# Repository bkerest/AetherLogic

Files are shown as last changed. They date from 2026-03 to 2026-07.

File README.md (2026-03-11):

# AetherLogic Firmware

Firmware για το σύστημα παρακολούθησης ποιότητας αέρα και θορύβου σε βιομηχανικά περιβάλλοντα βαφής αλουμινίου.

## Επισκόπηση

Το σύστημα αποτελείται από:
- **Sensor Nodes** (ESP32-C3): Αυτόνομοι κόμβοι με μπαταρία που συλλέγουν δεδομένα από αισθητήρες
- **Gateway** (ESP32-S3): Κεντρική πύλη που λαμβάνει δεδομένα μέσω LoRa και τα προωθεί σε MQTT broker

## Hardware

### Sensor Node (ESP32-C3)
| Αισθητήρας | Μέτρηση |
|---|---|
| BME680 | Θερμοκρασία, Υγρασία, Πίεση, VOC |
| SCD40 | CO₂ |
| ZH03B | Σωματίδια (PM2.5, PM10) |
| INMP441 | Θόρυβος (I2S) |

### Gateway (ESP32-S3)
- SX1276 LoRa module
- WiFi σύνδεση με MQTT broker

### LoRa Configuration
- Συχνότητα: 868 MHz
- Spreading Factor: SF10
- Bandwidth: 125 kHz

## Δομή Repository

```
aetherlogic/firmware/
├── sensor-node/          # ESP32-C3 firmware
│   └── sensor-node.ino
├── gateway/              # ESP32-S3 firmware
│   └── gateway.ino
└── docs/
    └── pinouts.md
    └──docs/gerber/
        └── Gerber_GateWay.zip        # Σχέδια πλακέτας Πύλης
        └── Gerber_Node.zip           # Σχέδια πλακέτας αισθητήρων
        └── Gerber_Node_Power.zip     # Σχέδια πλακέτας τροφοδοσίας αισθητήρων
    └──docs/grafana/
        └── AetherLogic - Main Dashboard-1773261228574.json     # Κυρίως Πίνακας ελέγχου με κάτοψη εργοστασίου
        └── AetherLogic - Nodes Dashboard-1773261255099.json    # Πίνακας ελέγχου ανά κόμβο
        └── alert-rules-1773261341571.json                      # Κανόνες ειδοποιήσεων
        └── contact-points-1773261295272.json                   # Σημεία επαφής
        └── elvial_floorplan.svg                                # Κάτοψη εργοστασίου σε μορφή svg
        └── JS_Initialization.js                                # Αρχείο αρχικοποίησης Main Dashboard
        └── JS_Render_Code.js                                   # Αρχείο λειτουργίας js/react Main Dashboard
    └──docs/influx/
        └── influxdb-schema.md    # Λειτουργικά ερωτήματα Influx και downsampling
    └──docs/monitoring/
        └── docker-compose.yml    # Αρχείο ρυθμίσων docker station
    └──docs/stl/
        └── GATEWAY_BOTTOM.stl    # Εκτυπώσιμο (3D) περιβλήματος πύλης
        └── GATEWAY_CAP.stl       # Εκτυπώσιμο (3D) καπακιού πύλης
        └── NODE_BOTTOM.stl       # Εκτυπώσιμο (3D) περιβλήματος κόμβου
        └── NODE_CAP.stl          # Εκτυπώσιμο (3D) καπακιού κόμβου
        └── PCB_HOLDER.stl        # Εκτυπώσιμο (3D) βάσης στήριξης PCB
    └──docs/telegraf/
        └── telegraf.conf         # Αρχείο ρυθμίσεων telegraf
```

## Απαιτήσεις

- Arduino IDE 2.x
- ESP32 Board Package (by Espressif)
- Βιβλιοθήκες:
  - RadioLib (LoRa)
  - Adafruit BME680
  - Sensirion SCD4x
  - PubSubClient (MQTT)

## Εγκατάσταση

1. Άνοιξε το Arduino IDE
2. Εγκατάστησε το ESP32 board package:
   - File → Preferences → Additional Board Manager URLs:
   - `https://raw.githubusercontent.com/espressif/arduino-esp32/gh-pages/package_esp32_index.json`
3. Tools → Board → ESP32 → επίλεξε το αντίστοιχο board
4. Άνοιξε τον φάκελο `sensor-node/` ή `gateway/` ανάλογα

## Backend

Τα δεδομένα αποστέλλονται σε MQTT broker (EMQX) και αποθηκεύονται σε InfluxDB μέσω Telegraf. Visualization με Grafana.

Dashboard: https://aetherlogic.eu/

## Άδεια

Μέρος πτυχιακής εργασίας - ΕΑΠ - ΠΛΗ40

## Συγγραφέας

Βασίλειος Κερεστετζής - Υπό την επίβλεψη του Καθηγητή Μηνά Δασυγένη

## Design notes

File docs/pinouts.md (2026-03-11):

# Pinouts Documentation

## Sensor Node - ESP32-C3

### Analog Inputs (ADC1)
| Λειτουργία | ESP32-C3 Pin | Σημείωση |
|---|---|---|
| Battery | GPIO0 | ADC1_CH0 |
| Microphone | GPIO1 | ADC1_CH1 |

### Power Control
| Λειτουργία | ESP32-C3 Pin | Σημείωση |
|---|---|---|
| ZH03B Power  | GPIO5 | Boost EN |
| Sensors Power| GPIO8 | P-MOS Gate |

### I2C Bus (BME680, SCD40)
| Σήμα | ESP32-C3 Pin |
|---|---|
| SDA  | GPIO19 |
| SCL  | GPIO18 |

### ZH03B (UART - RX only)
| ZH03B Pin | ESP32-C3 Pin | Σημείωση |
|---|---|---|
| TXD | GPIO4 | ZH_RX_PIN |
| VCC | 5V (via boost) | Ελέγχεται από GPIO5 |
| GND | GND | |

### LoRa Module (SX1276)
| SX1276 Pin | ESP32-C3 Pin | Σημείωση |
|---|---|---|
| VCC | 3.3V | |
| GND | GND | |
| SCK | GPIO6 | SPI CLK  |
| MISO | GPIO2 | SPI MISO |
| MOSI | GPIO7 | SPI MOSI |
| NSS | GPIO10 | SPI CS |
| RST | GPIO9 | Reset |
| DIO0 | GPIO3 | IRQ |

---

## Gateway - ESP32-S3

### LoRa Module (SX1276) - FSPI
| SX1276 Pin | ESP32-S3 Pin | Σημείωση |
|---|---|---|
| VCC | 3.3V | |
| GND | GND | |
| SCK | GPIO4 | FSPI CLK |
| MISO | GPIO5 | FSPI MISO|
| MOSI | GPIO6 | FSPI MOSI|
| NSS | GPIO7 | FSPI CS  |
| RST | GPIO15 | Reset |
| DIO0 | GPIO16 | IRQ |

### TFT Display (ST7789 320x240) - HSPI
| TFT Pin | ESP32-S3 Pin | Σημείωση |
|---|---|---|
| SCLK | GPIO9 | HSPI CLK |
| MOSI | GPIO10 | HSPI MOSI|
| CS | GPIO13 | Chip Select |
| DC | GPIO12 | Data/Command |
| RST | GPIO11 | Reset |
| BL | GPIO41 | Backlight (timeout: 20s) |

### User Interface
| Λειτουργία | ESP32-S3 Pin | Σημείωση |
|---|---|---|
| Button | GPIO0 | Long press: 3s |

---

## I2C Addresses (Sensor Node)

| Συσκευή | Address |
|---|---|
| BME680  | 0x77 |
| SCD40 | 0x62 |

---

## Configuration Defaults

### Sensor Node
| Παράμετρος | Τιμή | Σημείωση |
|---|---|---|
| Node ID | 1 | |
| Sleep Time | 300s | 5 λεπτά  |
| Warmup Time| 25s  | |
| LoRa Profile| 2 | |
| AES Key | "MySecretKey12345" | 16 bytes |

### Gateway
| Παράμετρος | Τιμή | Σημείωση |
|---|---|---|
| MQTT Server| d0a16fcc.ala.eu-central-1.emqxsl.com | EMQX Cloud |
| MQTT Port  | 8883 | TLS |
| MQTT Topic | lora/sensors | |
| LoRa Profile| 3 | SF10 Long Range |
| Hostname | s3gateway | |
| NTP Server | pool.ntp.org | |
| Timezone | GMT+2 (+DST) | Ελλάδα |

---

## Σημειώσεις

1. **ESP32-C3**: Χρησιμοποιεί P-MOS για power control των αισθητήρων (GPIO8)
2. **ESP32-S3**: Διπλό SPI bus - FSPI για LoRa, HSPI για TFT
3. **SX1276**: Λειτουργεί στα 3.3V - ΜΗΝ συνδέσετε σε 5V
4. **ZH03B**: Χρειάζεται 5V από boost converter (ελέγχεται από GPIO5)
5. **TFT Backlight**: Αυτόματο timeout μετά από 20s αδράνειας
6. **Magic Number**: 0xCAFE για validation των settings στη μνήμη

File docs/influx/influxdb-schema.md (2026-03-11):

# InfluxDB Schema & Data Pipeline - AetherLogic IoT System

## Περιεχόμενα
1. [Γενική Επισκόπηση](#γενική-επισκόπηση)
2. [Buckets & Retention Policies](#buckets--retention-policies)
3. [Measurements & Schema](#measurements--schema)
4. [Downsampling Tasks](#downsampling-tasks)
5. [Queries & Aggregations](#queries--aggregations)
6. [Storage Calculations](#storage-calculations)

---

## Γενική Επισκόπηση

Το σύστημα AetherLogic χρησιμοποιεί **InfluxDB v2** ως time-series database για την αποθήκευση δεδομένων αισθητήρων και gateway health metrics.

### Ροή Δεδομένων

```
┌─────────────┐     LoRa      ┌─────────┐    MQTT     ┌────────────┐
│ Sensor Node │ ──────────────>│ Gateway │ ──────────> │ EMQX Broker│
└─────────────┘   868MHz       └─────────┘   TLS:8883  └────────────┘
                                                              │
                                                              │ MQTT
                                                              ▼
                                                        ┌──────────┐
                                                        │ Telegraf │
                                                        └──────────┘
                                                              │
                                                              │ Line Protocol
                                                              ▼
┌─────────────────────────────────────────────────────────────────────┐
│                          InfluxDB v2                                │
├─────────────────────────────────────────────────────────────────────┤
│  Bucket: eap_plh40       (90 days)   ← Raw 5min data               │
│  Bucket: eap_plh40_1h    (1 year)    ← Hourly aggregates           │
│  Bucket: eap_plh40_1d    (5 years)   ← Daily aggregates            │
└─────────────────────────────────────────────────────────────────────┘
                                 │
                                 │ Flux Queries
                                 ▼
                           ┌──────────┐
                           │ Grafana  │
                           └──────────┘
```

---

## Buckets & Retention Policies

### Σχεδιασμός Buckets

Το σύστημα χρησιμοποιεί **3-tier retention strategy** για βέλτιστη χρήση αποθηκευτικού χώρου:

| Bucket | Retention | Data Interval | Purpose | Requirement |
|---|---|---|---|---|
| `eap_plh40` | 90 days | 5 minutes | Recent detailed data | FR-STOR-02 (partial) |
| `eap_plh40_1h` | 1 year | 1 hour avg | Historical trends | FR-STOR-02 (≥1 year) ✅ |
| `eap_plh40_1d` | 5 years | 1 day avg | Long-term analysis | FR-STOR-04 ✅ |

### Δημιουργία Buckets (InfluxDB CLI)

```bash
# Bucket 1: Raw data (90 days)
influx bucket create \
  --name eap_plh40 \
  --org "Hellenic Open University" \
  --retention 90d

# Bucket 2: Hourly aggregates (1 year)
influx bucket create \
  --name eap_plh40_1h \
  --org "Hellenic Open University" \
  --retention 365d

# Bucket 3: Daily aggregates (5 years)
influx bucket create \
  --name eap_plh40_1d \
  --org "Hellenic Open University" \
  --retention 1825d
```

### Δημιουργία Buckets (InfluxDB UI)

1. Ανοίξτε InfluxDB UI: `http://192.168.2.5:8086`
2. Πλοηγηθείτε: **Data** → **Buckets**
3. Κάντε κλικ: **+ Create Bucket**
4. Συμπληρώστε:
   - **Name**: `eap_plh40`
   - **Delete Data**: **Older than 90 days**
   - **Organization**: `Hellenic Open University`
5. Επαναλάβετε για `eap_plh40_1h` (365d) και `eap_plh40_1d` (1825d)

---

## Measurements & Schema

### Measurement 1: `air_quality`

Δεδομένα αισθητήρων από LoRa nodes.

#### Tags (Indexed)

| Tag | Type | Description | Example |
|-----|---|---|---|
| `id` | string | Node ID (από device configuration) | "1", "2", "3" |
| `gw` | string | Gateway ID (ESP32-S3 MAC-based) | "ESP32S3ABC123" |
| `node` | string | Friendly node name | "node_01", "FactoryNode_01" |

#### Fields (Not Indexed)

| Field | Type | Unit | Description | Range |
|---|---|---|---|---|
| `t` | float | °C | Temperature | -40 to 85 |
| `h` | float | % | Relative Humidity | 0 to 100 |
| `p` | float | hPa | Atmospheric Pressure | 300 to 1100 |
| `alt` | float | m | Calculated Altitude | -500 to 9000 |
| `iaq` | float | - | Indoor Air Quality Index | 0 to 500 |
| `tvoc` | float | kΩ | Gas Resistance (BME680) | 0 to 500 |
| `co2` | integer | ppm | CO₂ Concentration (SCD40) | 400 to 5000 |
| `pm1` | integer | µg/m³ | PM1.0 Particulate Matter | 0 to 1000 |
| `pm25` | integer | µg/m³ | PM2.5 Particulate Matter | 0 to 1000 |
| `pm10` | integer | µg/m³ | PM10 Particulate Matter | 0 to 1000 |
| `noise` | float | dB SPL | Noise Level | 30 to 130 |
| `batt` | float | V | Battery Voltage | 2.8 to 4.2 |
| `rssi` | integer | dBm | LoRa Signal Strength | -120 to -30 |

#### Example Line Protocol

```
air_quality,id=1,gw=ESP32S3ABC123,node=node_01 t=24.5,h=45.2,p=1013.25,alt=120.5,iaq=125,tvoc=45.23,co2=450,pm1=8,pm25=12,pm10=25,noise=65.3,batt=3.82,rssi=-85 1706097045000000000
```

#### Example JSON Payload (from MQTT)

```json
{
  "timestamp": "2024-01-24T14:30:45+02:00",
  "gw": "ESP32S3ABC123",
  "id": 1,
  "node": "node_01",
  "t": 24.5,
  "h": 45.2,
  "p": 1013.25,
  "alt": 120.5,
  "iaq": 125,
  "tvoc": 45.23,
  "co2": 450,
  "pm1": 8,
  "pm25": 12,
  "pm10": 25,
  "noise": 65.3,
  "batt": 3.82,
  "rssi": -85
}
```

---

### Measurement 2: `gateway_health`

Gateway heartbeat και health metrics (κάθε 5 λεπτά).

#### Tags

| Tag | Type | Description | Example |
|-----|---|---|---|
| `gw` | string | Gateway ID | "ESP32S3ABC123" |
| `type` | string | Message type | "heartbeat" |
| `fw` | string | Firmware version | "2.5.2" |

#### Fields

| Field | Type | Unit | Description |
|---|---|---|---|
| `uptime` | integer | seconds | Time since boot |
| `heap` | integer | bytes | Free heap memory |
| `wifi_rssi` | integer | dBm | WiFi signal strength |
| `lora_packets` | integer | count | Total LoRa packets received |
| `buffer` | integer | count | Buffered MQTT messages |
| `ntp_synced` | boolean | - | NTP synchronization status |
| `lora_ok` | boolean | - | LoRa module initialization status |

#### Example Line Protocol

```
gateway_health,gw=ESP32S3ABC123,type=heartbeat,fw=2.5.2 uptime=86400,heap=245760,wifi_rssi=-65,lora_packets=1440,buffer=0,ntp_synced=true,lora_ok=true 1706097045000000000
```

---

## Downsampling Tasks

Τα **InfluxDB Tasks** εκτελούν αυτόματα aggregations για downsampling.

### Task 1: Hourly Downsampling

**Σκοπός**: Υπολογισμός ωριαίων μέσων όρων από raw data (5min).

**Συχνότητα**: Κάθε ώρα (στο :05 λεπτό για να έχει ολοκληρωθεί η προηγούμενη ώρα).

**Flux Script**:

```flux
// Task: Downsample to 1-hour averages
option task = {
  name: "downsample_1h_air_quality",
  every: 1h,
  offset: 5m  // Run at :05 past the hour
}

from(bucket: "eap_plh40")
  |> range(start: -2h, stop: -1h)  // Process previous hour
  |> filter(fn: (r) => r._measurement == "air_quality")
  |> aggregateWindow(
      every: 1h,
      fn: mean,
      createEmpty: false
    )
  |> to(
      bucket: "eap_plh40_1h",
      org: "Hellenic Open University"
    )
```

**Δημιουργία Task (InfluxDB UI)**:

1. **Tasks** → **Create Task**
2. **Name**: `downsample_1h_air_quality`
3. **Every**: `1h`
4. **Offset**: `5m`
5. Paste Flux script
6. **Save**

---

### Task 2: Daily Downsampling

**Σκοπός**: Υπολογισμός ημερήσιων μέσων όρων από hourly data.

**Συχνότητα**: Κάθε μέρα στις 00:10.

**Flux Script**:

```flux
// Task: Downsample to 1-day averages
option task = {
  name: "downsample_1d_air_quality",
  every: 1d,
  offset: 10m  // Run at 00:10
}

from(bucket: "eap_plh40_1h")
  |> range(start: -2d, stop: -1d)  // Process previous day
  |> filter(fn: (r) => r._measurement == "air_quality")
  |> aggregateWindow(
      every: 1d,
      fn: mean,
      createEmpty: false
    )
  |> to(
      bucket: "eap_plh40_1d",
      org: "Hellenic Open University"
    )
```

---

### Task 3: Gateway Health Downsampling (Optional)

**Σκοπός**: Υπολογισμός ημερήσιων aggregations για gateway metrics.

```flux
option task = {
  name: "downsample_1d_gateway_health",
  every: 1d,
  offset: 15m
}

from(bucket: "eap_plh40")
  |> range(start: -2d, stop: -1d)
  |> filter(fn: (r) => r._measurement == "gateway_health")
  |> aggregateWindow(
      every: 1d,
      fn: mean,  // or max/min depending on field
      createEmpty: false
    )
  |> to(
      bucket: "eap_plh40_1d",
      org: "Hellenic Open University"
    )
```

---

## Queries & Aggregations

### Basic Queries (Flux)

#### Query 1: Latest Reading από κάθε Node

```flux
from(bucket: "eap_plh40")
  |> range(start: -1h)
  |> filter(fn: (r) => r._measurement == "air_quality")
  |> filter(fn: (r) => r._field == "t" or r._field == "h" or r._field == "co2")
  |> last()
  |> pivot(rowKey:["_time"], columnKey: ["_field"], valueColumn: "_value")
```

#### Query 2: Μέση Θερμοκρασία τελευταίας εβδομάδας

```flux
from(bucket: "eap_plh40_1h")  // Use hourly data for speed
  |> range(start: -7d)
  |> filter(fn: (r) => r._measurement == "air_quality")
  |> filter(fn: (r) => r._field == "t")
  |> mean()
  |> group(columns: ["node"])
```

#### Query 3: PM2.5 Max per Day (Last Month)

```flux
from(bucket: "eap_plh40_1h")
  |> range(start: -30d)
  |> filter(fn: (r) => r._measurement == "air_quality")
  |> filter(fn: (r) => r._field == "pm25")
  |> aggregateWindow(every: 1d, fn: max)
```

#### Query 4: Gateway Uptime & Health

```flux
from(bucket: "eap_plh40")
  |> range(start: -24h)
  |> filter(fn: (r) => r._measurement == "gateway_health")
  |> filter(fn: (r) => r._field == "uptime" or r._field == "heap")
  |> last()
```

---

### Advanced Aggregations

#### Compute Moving Average (7-day)

```flux
from(bucket: "eap_plh40_1d")
  |> range(start: -90d)
  |> filter(fn: (r) => r._measurement == "air_quality")
  |> filter(fn: (r) => r._field == "co2")
  |> movingAverage(n: 7)  // 7-day moving average
```

#### Detect Threshold Violations (PM2.5 > 35 µg/m³)

```flux
from(bucket: "eap_plh40")
  |> range(start: -24h)
  |> filter(fn: (r) => r._measurement == "air_quality")
  |> filter(fn: (r) => r._field == "pm25")
  |> filter(fn: (r) => r._value > 35)  // WHO 24h guideline
  |> group(columns: ["node"])
  |> count()
```

#### Correlation Analysis (Temperature vs CO2)

```flux
temp = from(bucket: "eap_plh40_1h")
  |> range(start: -7d)
  |> filter(fn: (r) => r._measurement == "air_quality")
  |> filter(fn: (r) => r._field == "t")
  |> drop(columns: ["_measurement"])

co2 = from(bucket: "eap_plh40_1h")
  |> range(start: -7d)
  |> filter(fn: (r) => r._measurement == "air_quality")
  |> filter(fn: (r) => r._field == "co2")
  |> drop(columns: ["_measurement"])

join(
  tables: {temp: temp, co2: co2},
  on: ["_time", "node", "gw"]
)
```

---

## Storage Calculations

### Data Volume Estimation

**Assumptions**:
- **Sensor Nodes**: 5
- **Measurements per Node**: 13 fields (t, h, p, alt, iaq, tvoc, co2, pm1, pm25, pm10, noise, batt, rssi)
- **Sampling Interval**: 5 minutes
- **InfluxDB Point Size**: ~8 bytes per field (average)

#### Tier 1: Raw Data (90 days @ 5min)

```
Points per node per day:
  13 fields × (60 min / 5 min) × 24 hours = 13 × 12 × 24 = 3,744 points/day

Points per node for 90 days:
  3,744 × 90 = 336,960 points

Total points (5 nodes):
  336,960 × 5 = 1,684,800 points

Storage (approximate):
  1,684,800 × 8 bytes = 13.5 MB (compressed: ~3-5 MB)
```

#### Tier 2: Hourly Averages (1 year)

```
Points per node per day:
  13 fields × 24 hours = 312 points/day

Points per node for 1 year:
  312 × 365 = 113,880 points

Total points (5 nodes):
  113,880 × 5 = 569,400 points

Storage:
  569,400 × 8 bytes = 4.6 MB (compressed: ~1-2 MB)
```

#### Tier 3: Daily Averages (5 years)

```
Points per node per day:
  13 fields × 1 = 13 points/day

Points per node for 5 years:
  13 × 365 × 5 = 23,725 points

Total points (5 nodes):
  23,725 × 5 = 118,625 points

Storage:
  118,625 × 8 bytes = 0.95 MB (negligible)
```

#### Total Storage

```
Tier 1 (90d raw):     ~3-5 MB
Tier 2 (1y hourly):   ~1-2 MB
Tier 3 (5y daily):    ~1 MB
----------------------------------
TOTAL:                ~5-8 MB (very manageable!)
```

**Συμπέρασμα**: Το σύστημα με 5 sensor nodes καταναλώνει **<10 MB** για 5 χρόνια ιστορικών δεδομένων με downsampling. Αυτό είναι εξαιρετικά αποδοτικό.

---

## Backup & Restore

### Backup Bucket (InfluxDB CLI)

```bash
# Backup all data from bucket
influx backup /backup/path \
  --bucket eap_plh40 \
  --org "Hellenic Open University"

# Backup specific time range
influx backup /backup/path \
  --bucket eap_plh40 \
  --start 2024-01-01T00:00:00Z \
  --stop 2024-12-31T23:59:59Z
```

### Restore Bucket

```bash
influx restore /backup/path \
  --bucket eap_plh40 \
  --org "Hellenic Open University"
```

### Automated Daily Backup (Cron)

```bash
# Add to crontab: crontab -e
0 2 * * * /usr/bin/influx backup /mnt/backups/influxdb/$(date +\%Y\%m\%d) --bucket eap_plh40 --org "Hellenic Open University"
```

---

## Monitoring & Maintenance

### Health Checks

```bash
# Check bucket size
influx bucket list --org "Hellenic Open University"

# Check task status
influx task list --org "Hellenic Open University"

# View task logs
influx task log list --task-id <TASK_ID>

# Check cardinality (unique tag combinations)
influx cardinality --bucket eap_plh40
```

### Performance Tuning

1. **Indexing**: Tags are automatically indexed, fields are not
2. **Cardinality**: Keep tag cardinality low (<100K unique combinations)
3. **Retention**: Aggressive retention policies reduce storage and improve query speed
4. **Downsampling**: Use pre-aggregated buckets for historical queries

---

## Ικανοποίηση Απαιτήσεων

| Requirement ID | Description | Implementation | Status |
|---|---|---|---|
| FR-STOR-01 | Time-series database | InfluxDB v2 | ✅ |
| FR-STOR-02 | Data retention ≥1 year | `eap_plh40_1h` bucket (365d) | ✅ |
| FR-STOR-03 | Time & node queries | Tags: `id`, `node`, `gw` + timestamp | ✅ |
| FR-STOR-04 | Downsampling | Tasks: 1h, 1d aggregations | ✅ |
| FR-STOR-05 | Automatic deletion | Retention policies (90d, 365d, 1825d) | ✅ |
| FR-STOR-06 | Backup/restore | InfluxDB CLI backup | ✅ (Could Have) |

---

## Πηγές

- [InfluxDB v2 Documentation](https://docs.influxdata.com/influxdb/v2.0/)
- [Flux Language Guide](https://docs.influxdata.com/flux/v0.x/)
- [Telegraf MQTT Consumer](https://github.com/influxdata/telegraf/tree/master/plugins/inputs/mqtt_consumer)
- [Time-Series Data Retention Best Practices](https://www.influxdata.com/blog/tldr-influxdb-tech-tips-august-27-2020/)

---

**Document Version**: 1.0
**Last Updated**: 24 Ιανουαρίου 2026
**Author**: Vasilis Kerestetzis AetherLogic Project - Hellenic Open University

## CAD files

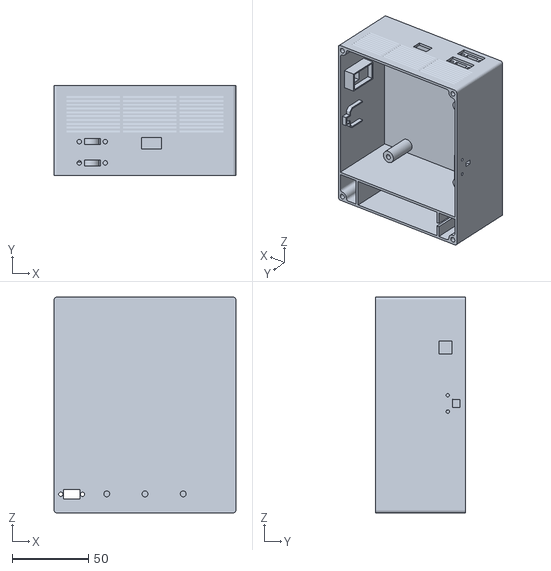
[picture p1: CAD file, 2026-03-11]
docs/stl/NODE_BOTTOM.stl
119.0 x 59.0 x 141.4

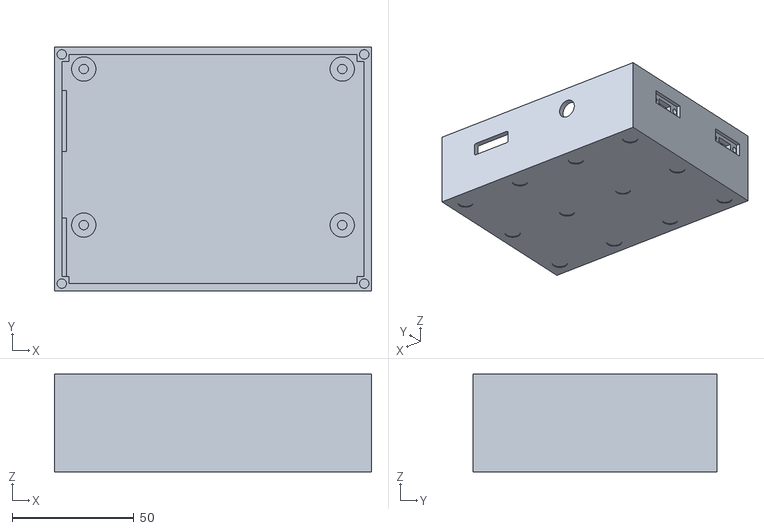
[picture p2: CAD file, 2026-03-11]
docs/stl/GATEWAY_BOTTOM.stl
130.0 x 100.0 x 40.0

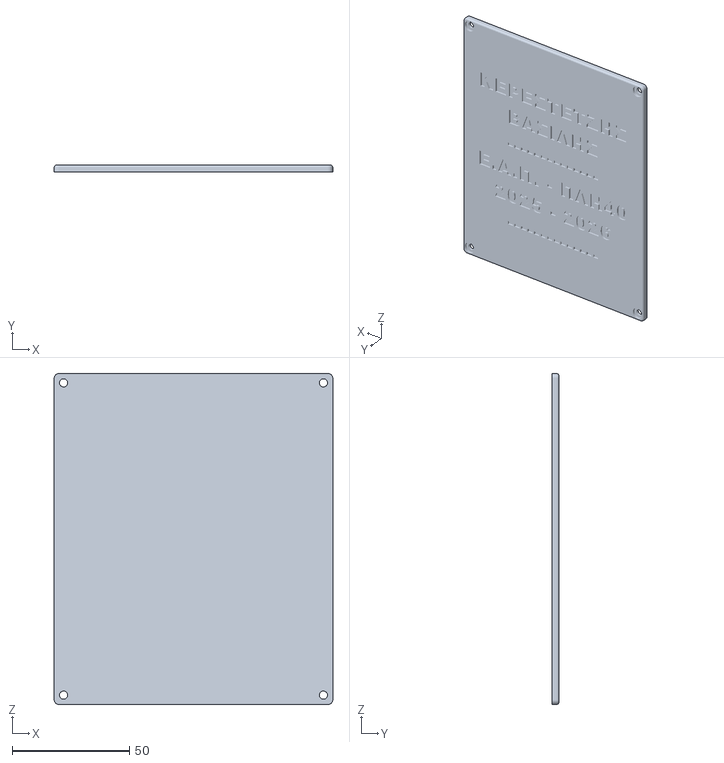
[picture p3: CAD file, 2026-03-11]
docs/stl/NODE_CAP.stl
119.0 x 3.00 x 141.4

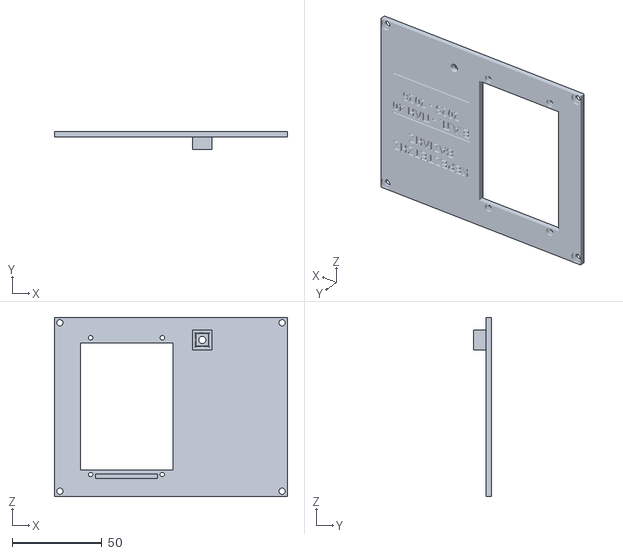
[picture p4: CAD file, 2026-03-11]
docs/stl/GATEWAY_CAP.stl
130.0 x 10.0 x 100.0

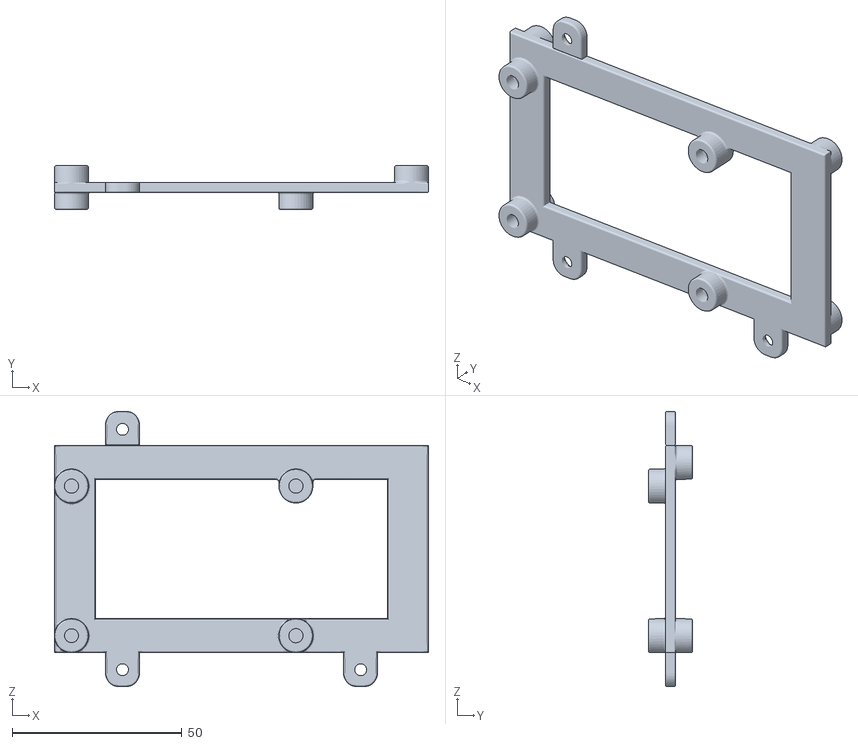
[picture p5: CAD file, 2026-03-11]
docs/stl/PCB_HOLDER.stl
110.0 x 13.0 x 81.0

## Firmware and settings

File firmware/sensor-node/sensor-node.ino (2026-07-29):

// AetherLogic Sensor Node Firmware
// IoT air quality monitoring for industrial aluminum powder coating environments
// Part of undergraduate thesis (Polytechnic School)
//
// Hardware: ESP32-C3 + SX1276 LoRa + BME680 + SCD40 + ZH03B + Mic
// Cycle: Wake -> UVLO Check -> Measure -> Encrypt -> LoRa TX -> Deep Sleep

#include <math.h>
#include <Wire.h>
#include <SPI.h>
#include <LoRa.h>
#include <Adafruit_Sensor.h>
#include "Adafruit_BME680.h"
#include "SparkFun_SCD4x_Arduino_Library.h"
#include <HardwareSerial.h>
#include <WiFi.h>
#include "mbedtls/aes.h"
#include <driver/gpio.h>
#include <Preferences.h>

// ESP32-C3 RTC_CNTL_BROWN_OUT_REG address and enable bit
#define RTC_CNTL_BROWN_OUT_REG  0x600080D8
#define RTC_CNTL_BROWN_OUT_ENA  (1 << 30)

// ESP32-C3 RTC_CNTL_BROWN_OUT_REG at 0x600080D8, bit 30 is enable
#define RTC_CNTL_BROWN_OUT_REG  0x600080D8
#define RTC_CNTL_BROWN_OUT_ENA  (1 << 30)

// --- Pin Assignments (ESP32-C3) ---
#define BAT_PIN       0    // ADC1_CH0 - Battery voltage divider
#define MIC_PIN       1    // ADC1_CH1 - Microphone amplifier output

#define ZH_PWR_PIN    5    // 5V boost enable (HIGH = ON)
#define SENS_PWR_PIN  8    // P-MOSFET gate for 3.3V sensor rail (LOW = ON)

#define I2C_SDA       19
#define I2C_SCL       18

#define ZH_RX_PIN     4    // ZH03B UART RX

#define LORA_SCK      6
#define LORA_MISO     2
#define LORA_MOSI     7
#define LORA_CS       10
#define LORA_RST      9
#define LORA_DIO0     3

// --- Default Configuration (used on first boot, overridden by NVS) ---
#define DEFAULT_ID      1
#define DEFAULT_NAME    "Node"
#define DEFAULT_SLEEP   300        // seconds
#define DEFAULT_WARMUP  25         // seconds
#define DEFAULT_VOLT_F  2.6        // ADC mV to battery V factor
#define DEFAULT_DB_OFF  68.0       // Microphone dB calibration offset
#define DEFAULT_TMP_OFF 0.0        // Temperature offset (°C)
#define DEFAULT_CO2_OFF 0          // CO2 offset (ppm)
#define DEFAULT_AES     "MySecretKey12345"  // AES-128 key (16 bytes)
#define MAGIC_NUMBER    0xCAFE     // Packet header magic
#define DEFAULT_BASELINE 50000.0   // Initial BME680 gas baseline (Ohm)
#define DEFAULT_LORA_PROFILE 2     // BALANCED

// --- Software UVLO (Undervoltage Lockout) ---
#define UVLO_THRESHOLD  2.95       // Minimum battery voltage (V) to proceed
#define UVLO_SLEEP_HR   12         // Deep sleep duration (hours) when undervoltage

// LoRa Profiles: 1=ECO(SF7,14dBm) 2=BALANCED(SF9,17dBm) 3=LONG(SF10,20dBm) 4=EXTREME(SF12,20dBm)

// --- Global Objects ---
Preferences prefs;
Adafruit_BME680 bme;
SCD4x scd4x;
HardwareSerial zhSerial(1);

// Runtime config (loaded from NVS)
uint16_t cfg_deviceId;
String   cfg_deviceName;
uint32_t cfg_sleepSec;
uint32_t cfg_warmupSec;
float    cfg_voltFactor;
float    cfg_dbOffset;
float    cfg_tempOffset;
float    cfg_pressOffset;
int16_t  cfg_co2Offset;
String   cfg_aesKey;
float    current_baseline;
uint8_t  cfg_loraProfile;

uint32_t currentPacketId = 0;

// Retained across deep sleep (not across power loss)
RTC_DATA_ATTR int decay_counter = 0;

// LoRa payload: 48 bytes = 3x AES-128 blocks, no padding needed
struct SecurePacket {
  uint16_t magic;
  uint16_t deviceId;
  uint32_t packetId;
  float voltage;
  float noise_db;
  float temp;
  float hum;
  float pressure;
  float iaq;
  uint16_t co2;
  uint16_t pm1;
  uint16_t pm25;
  uint16_t pm10;
  float tvoc;
  uint8_t padding[4];
};

struct DustData {
  uint16_t pm1_0;
  uint16_t pm2_5;
  uint16_t pm10;
};

// --- IAQ Calculation ---
// Composite air quality score (25=best, 500=worst) from BME680 gas resistance
// and humidity. Based on Bosch application note approach (without BSEC library).
//
// Humidity contributes 25% (optimal band: 38-42% RH).
// Gas resistance contributes 75%, normalized against a dynamic baseline
// that tracks the highest resistance seen in clean air.
float calculateIAQ(float gasResistance, float humidity, float baseline) {
  float hum_reference = 40.0;
  float hum_weighting = 0.25;
  float gas_weighting = 0.75;

  float current_hum_contribution = 0;
  if (humidity >= 38 && humidity <= 42)
    current_hum_contribution = 0.25 * 100;
  else {
    if (humidity < 38) current_hum_contribution = 0.25/hum_reference * humidity * 100;
    else current_hum_contribution = ((-0.25/(100-hum_reference) * humidity) + 0.416666) * 100;
  }

  float current_gas_contribution = 0;

  if (baseline < 5000) baseline = 5000;
  if (gasResistance > baseline) gasResistance = baseline;

  current_gas_contribution = (gas_weighting / (baseline - 5000) * (gasResistance - 5000)) * 100;

  float iaq_score = current_hum_contribution + current_gas_contribution;

  float final_iaq = 500.0 - (iaq_score * 4.75);
  if (final_iaq < 25) final_iaq = 25;

  return final_iaq;
}

// Configure SX1276 based on selected profile (1-4)
void applyLoRaProfile(uint8_t profile) {
  switch(profile) {
    case 1:
      LoRa.setSpreadingFactor(7);
      LoRa.setSignalBandwidth(125E3);
      LoRa.setCodingRate4(5);
      LoRa.setTxPower(14);
      Serial.println("LoRa Profile: ECO (SF7, 14dBm)");
      Serial.println("  Range: ~2km | TX Time: ~50ms | Power: LOW");
      break;

    case 2:
      LoRa.setSpreadingFactor(9);
      LoRa.setSignalBandwidth(125E3);
      LoRa.setCodingRate4(5);
      LoRa.setTxPower(17);
      Serial.println("LoRa Profile: LONG (SF10, 17dBm)");
      Serial.println("  Range: ~4km | TX Time: ~200ms | Power: MEDIUM");
      break;

    case 3:
      LoRa.setSpreadingFactor(10);
      LoRa.setSignalBandwidth(125E3);
      LoRa.setCodingRate4(6);
      LoRa.setTxPower(20);
      Serial.println("LoRa Profile: LONG (SF10, 20dBm)");
      Serial.println("  Range: ~8km | TX Time: ~400ms | Power: HIGH");
      break;

    case 4:
      LoRa.setSpreadingFactor(12);
      LoRa.setSignalBandwidth(125E3);
      LoRa.setCodingRate4(8);
      LoRa.setTxPower(20);
      Serial.println("LoRa Profile: EXTREME (SF12, 20dBm)");
      Serial.println("  Range: ~15km | TX Time: ~1.5s | Power: VERY HIGH");
      break;

    default:
      profile = 3;
      applyLoRaProfile(3);
      return;
  }

  LoRa.setSyncWord(0x12);
  LoRa.enableCrc();
}

// Load all config from NVS, use defaults on first boot
void loadSettings() {
  prefs.begin("node_cfg", true);
  cfg_deviceId   = prefs.getUShort("dev_id", DEFAULT_ID);
  cfg_deviceName = prefs.getString("dev_name", DEFAULT_NAME);
  cfg_sleepSec   = prefs.getUInt("sleep_s", DEFAULT_SLEEP);
  cfg_warmupSec  = prefs.getUInt("warm_s", DEFAULT_WARMUP);
  cfg_voltFactor = prefs.getFloat("v_fact", DEFAULT_VOLT_F);
  cfg_dbOffset   = prefs.getFloat("db_off", DEFAULT_DB_OFF);
  cfg_tempOffset = prefs.getFloat("t_off", DEFAULT_TMP_OFF);
  cfg_pressOffset = prefs.getFloat("p_off", 0.0);
  cfg_co2Offset  = prefs.getShort("co2_off", DEFAULT_CO2_OFF);
  cfg_aesKey     = prefs.getString("aes_key", DEFAULT_AES);
  cfg_loraProfile = prefs.getUChar("lora_prf", DEFAULT_LORA_PROFILE);

  current_baseline = prefs.getFloat("gas_base", DEFAULT_BASELINE);
  currentPacketId  = prefs.getUInt("pkt_cnt", 0);

  prefs.end();

  if (cfg_aesKey.length() != 16) cfg_aesKey = DEFAULT_AES;
  if (cfg_loraProfile < 1 || cfg_loraProfile > 4) cfg_loraProfile = 2;
}

void savePacketCounter(uint32_t cnt) {
  prefs.begin("node_cfg", false);
  prefs.putUInt("pkt_cnt", cnt);
  prefs.end();
}

void saveBaseline(float newBaseline) {
  prefs.begin("node_cfg", false);
  prefs.putFloat("gas_base", newBaseline);
  prefs.end();
  Serial.printf("Auto-Calib: New Gas Baseline Saved: %.0f Ohm\n", newBaseline);
}

// === SOFTWARE UVLO (Undervoltage Lockout) ===
// Checks battery voltage before any peripherals are powered.
// If below UVLO_THRESHOLD, shuts down all outputs and enters
// extended deep sleep (UVLO_SLEEP_HR hours) to:
//   1. Prevent brownout resets that parasitically enable the 5V boost
//   2. Stop further discharge below safe Li-ion cell voltage (~2.5V)
//   3. Allow TP4056 to charge cells unimpeded (if USB power connected)
// Returns true if voltage is OK, never returns if undervoltage (enters sleep).
bool checkUVLO() {
  analogSetAttenuation(ADC_11db);
  pinMode(BAT_PIN, INPUT);
  delay(10);

  // Average 4 readings for more stable measurement at low voltage
  uint32_t raw_sum = 0;
  for (int i = 0; i < 4; i++) {
    raw_sum += analogReadMilliVolts(BAT_PIN);
    delay(5);
  }
  uint32_t raw_uvlo = raw_sum / 4;
  float voltage_uvlo = (raw_uvlo * cfg_voltFactor) / 1000.0;

  if (voltage_uvlo >= UVLO_THRESHOLD) {
    Serial.printf("UVLO: Battery %.2fV OK (threshold %.2fV)\n",
                  voltage_uvlo, UVLO_THRESHOLD);
    return true;
  }

  // --- Undervoltage detected: enter protective deep sleep ---
  Serial.printf("UVLO: Battery %.2fV < %.2fV - entering %dh deep sleep\n",
                voltage_uvlo, UVLO_THRESHOLD, UVLO_SLEEP_HR);
  Serial.flush();

  // Ensure all power outputs are OFF before sleeping
  pinMode(ZH_PWR_PIN, OUTPUT);
  digitalWrite(ZH_PWR_PIN, LOW);         // 5V boost OFF
  pinMode(SENS_PWR_PIN, OUTPUT);
  digitalWrite(SENS_PWR_PIN, HIGH);       // P-MOSFET OFF (active-low)

  // Ground all other pins to prevent parasitic leakage
  const uint8_t pinsToGround[] = {
    MIC_PIN, I2C_SDA, I2C_SCL, ZH_RX_PIN,
    LORA_SCK, LORA_MISO, LORA_MOSI, LORA_CS, LORA_RST, LORA_DIO0
  };
  for (int i = 0; i < sizeof(pinsToGround); i++) {
    pinMode(pinsToGround[i], OUTPUT);
    digitalWrite(pinsToGround[i], LOW);
  }

  // Hold GPIO states during deep sleep
  gpio_hold_en((gpio_num_t)ZH_PWR_PIN);
  gpio_hold_en((gpio_num_t)SENS_PWR_PIN);
  gpio_deep_sleep_hold_en();

  // Sleep for UVLO_SLEEP_HR hours
  uint64_t uvlo_sleep_us = (uint64_t)UVLO_SLEEP_HR * 3600ULL * 1000000ULL;
  esp_sleep_enable_timer_wakeup(uvlo_sleep_us);
  esp_deep_sleep_start();

  // Never reached
  return false;
}

// Interactive serial configuration menu with optional calibration wizard.
// Press 'c' during the 3-second boot window to enter.
void configureMode() {
  while(Serial.available()) Serial.read();

  Serial.println("\n--- CONFIGURATION MENU ---");
  Serial.println("Note: Press ENTER to keep current value.");
  Serial.setTimeout(1000);

  prefs.begin("node_cfg", false);

  auto readInput = [](String prompt, String currentVal) -> String {
    Serial.print(prompt + " [" + currentVal + "]: ");

    unsigned long start = millis();
    while (!Serial.available()) {
        if (millis() - start > 60000) return currentVal;
        delay(10);
    }

    String str = Serial.readStringUntil('\n');
    str.trim();

    if (str.length() == 0) {
       Serial.println("Kept");
       return currentVal;
    }
    Serial.println(str);
    return str;
  };

  String input;

  input = readInput("Device ID (Numeric)", String(cfg_deviceId));
  if(input != "") prefs.putUShort("dev_id", (uint16_t)input.toInt());

  input = readInput("Device Name (e.g. Office 1)", cfg_deviceName);
  if(input != "") prefs.putString("dev_name", input);

  input = readInput("Sleep (sec)", String(cfg_sleepSec));
  if(input != "") prefs.putUInt("sleep_s", (uint32_t)input.toInt());

  input = readInput("Warmup (sec)", String(cfg_warmupSec));
  if(input != "") prefs.putUInt("warm_s", (uint32_t)input.toInt());

  // Calibration wizard: single-point offset calibration against reference instruments
  Serial.println("\n=== SENSOR CALIBRATION ===");
  input = readInput("Run Calibration Wizard? (y/n)", "n");

  if(input == "y") {
    Serial.println("\nPowering ON sensors for calibration...");

    pinMode(ZH_PWR_PIN, OUTPUT);
    digitalWrite(ZH_PWR_PIN, HIGH);
    pinMode(SENS_PWR_PIN, OUTPUT);
    digitalWrite(SENS_PWR_PIN, LOW);
    delay(500);

    Wire.begin(I2C_SDA, I2C_SCL);
    pinMode(MIC_PIN, INPUT);
    pinMode(BAT_PIN, INPUT);
    analogSetAttenuation(ADC_11db);
    delay(100);

    // Battery voltage - calibrate divider factor against multimeter
    Serial.println("\n--- Battery Voltage Calibration ---");
    uint32_t raw_bat = analogReadMilliVolts(BAT_PIN);
    float measured_v = (raw_bat * cfg_voltFactor) / 1000.0;
    Serial.printf("Current reading: %.2f V (raw: %d mV)\n", measured_v, raw_bat);
    Serial.printf("Current factor: %.2f\n", cfg_voltFactor);

    input = readInput("Enter TRUE voltage (from multimeter)", "");
    if(input != "") {
      float true_voltage = input.toFloat();
      float new_factor = (true_voltage * 1000.0) / raw_bat;
      prefs.putFloat("v_fact", new_factor);
      Serial.printf("New voltage factor: %.2f\n", new_factor);
      Serial.printf("Sensor will now read: %.2f V\n", true_voltage);
      cfg_voltFactor = new_factor;
    }

    // Temperature & Pressure (BME680)
    if (bme.begin() || bme.begin(0x76)) {
      bme.setTemperatureOversampling(BME680_OS_8X);
      bme.setHumidityOversampling(BME680_OS_2X);
      bme.setPressureOversampling(BME680_OS_16X);
      bme.setIIRFilterSize(BME680_FILTER_SIZE_3);
      bme.setGasHeater(320, 150);

      delay(2000);
      bme.performReading();

      Serial.println("\n--- Temperature Calibration ---");
      float measured_temp = bme.temperature;
      Serial.printf("Current reading: %.2f °C\n", measured_temp);
      Serial.printf("Current offset: %.2f °C\n", cfg_tempOffset);
      Serial.printf("Corrected: %.2f °C\n", measured_temp + cfg_tempOffset);

      input = readInput("Enter TRUE temperature (from reference thermometer)", "");
      if(input != "") {
        float true_temp = input.toFloat();
        float new_offset = true_temp - measured_temp;
        prefs.putFloat("t_off", new_offset);
        Serial.printf("New temp offset: %.2f °C\n", new_offset);
        Serial.printf("Sensor will now read: %.2f °C\n", measured_temp + new_offset);
        cfg_tempOffset = new_offset;
      }

      Serial.println("\n--- Pressure Calibration ---");
      Serial.println("Note: Your barometer may be faulty (~698 hPa)");
      float measured_press = bme.pressure / 100.0;
      Serial.printf("Current reading: %.2f hPa\n", measured_press);
      Serial.printf("Current offset: %.2f hPa\n", cfg_pressOffset);

      input = readInput("Enter TRUE pressure (from weather station)", "");
      if(input != "") {
        float true_pressure = input.toFloat();
        float press_offset = true_pressure - measured_press;
        prefs.putFloat("p_off", press_offset);
        Serial.printf("New pressure offset: %.2f hPa\n", press_offset);
        Serial.printf("Sensor will now read: %.2f hPa\n", measured_press + press_offset);
        cfg_pressOffset = press_offset;
      }
    } else {
      Serial.println("\nBME680 not found - skipping temp/pressure calibration");
    }

    // CO2 (SCD40)
    Serial.println("\n--- CO2 Calibration (SCD40) ---");
    if (scd4x.begin()) {
      scd4x.startPeriodicMeasurement();
      Serial.println("Waiting 5 sec for measurement...");
      delay(5000);

      if (scd4x.readMeasurement()) {
        uint16_t measured_co2 = scd4x.getCO2();
        Serial.printf("Current reading: %d ppm\n", measured_co2);
        Serial.printf("Current offset: %d ppm\n", cfg_co2Offset);
        Serial.printf("Corrected: %d ppm\n", measured_co2 + cfg_co2Offset);
        Serial.println("Tip: Fresh outdoor air = 400-420 ppm");

        input = readInput("Enter TRUE CO2 level (ppm)", "");
        if(input != "") {
          int16_t true_co2 = input.toInt();
          int16_t new_offset = true_co2 - measured_co2;
          prefs.putShort("co2_off", new_offset);
          Serial.printf("New CO2 offset: %d ppm\n", new_offset);
          Serial.printf("Sensor will now read: %d ppm\n", measured_co2 + new_offset);
          cfg_co2Offset = new_offset;
        }
      }
      scd4x.stopPeriodicMeasurement();
    } else {
      Serial.println("SCD40 not found!");
    }

    // Microphone dB calibration - sample for 5s, compare with SPL meter
    Serial.println("\n--- Microphone dB Calibration ---");
    Serial.println("Measuring for 5 seconds...");
    Serial.println("(Use calibrated SPL meter as reference)");

    double sum_db = 0.0;
    int count = 0;

    for(int i=0; i<100; i++) {
      unsigned long micStart = millis();
      unsigned int signalMax = 0;
      unsigned int signalMin = 4095;

      while (millis() - micStart < 50) {
        unsigned int sample = analogRead(MIC_PIN);
        if (sample < 4095) {
          if (sample > signalMax) signalMax = sample;
          if (sample < signalMin) signalMin = sample;
        }
      }

      double volts_mic = ((signalMax - signalMin) * 2.5) / 4095.0;
      double db = 20.0 * log10(volts_mic + 0.001) + cfg_dbOffset;
      sum_db += db;
      count++;
    }

    float avg_db = sum_db / count;
    Serial.printf("Current reading: %.1f dB\n", avg_db);
    Serial.printf("Current offset: %.1f\n", cfg_dbOffset);

    input = readInput("Enter TRUE dB level (from SPL meter)", "");
    if(input != "") {
      float true_db = input.toFloat();
      float new_offset = true_db - (avg_db - cfg_dbOffset);
      prefs.putFloat("db_off", new_offset);
      Serial.printf("New dB offset: %.1f\n", new_offset);
      cfg_dbOffset = new_offset;
    }

    digitalWrite(ZH_PWR_PIN, LOW);
    digitalWrite(SENS_PWR_PIN, HIGH);

    Serial.println("\n=== Calibration Complete ===\n");
  } else {
    // Manual offset entry without live sensors
    Serial.println("\nManual offset configuration:");

    input = readInput("Volt Factor", String(cfg_voltFactor));
    if(input != "") prefs.putFloat("v_fact", input.toFloat());

    input = readInput("Temp Offset", String(cfg_tempOffset));
    if(input != "") prefs.putFloat("t_off", input.toFloat());

    input = readInput("Pressure Offset", String(cfg_pressOffset));
    if(input != "") prefs.putFloat("p_off", input.toFloat());

    input = readInput("dB Offset", String(cfg_dbOffset));
    if(input != "") prefs.putFloat("db_off", input.toFloat());

    input = readInput("CO2 Offset", String(cfg_co2Offset));
    if(input != "") prefs.putShort("co2_off", (int16_t)input.toInt());
  }

  input = readInput("AES Key (16 chars)", cfg_aesKey);
  if (input.length() == 16) prefs.putString("aes_key", input);

  Serial.println("\n--- LoRa Profile Selection ---");
  Serial.println("1: ECO      - ~2km range, LOW power (SF7, 14dBm)");
  Serial.println("2: BALANCED - ~4km range, MEDIUM power (SF9, 17dBm) [DEFAULT]");
  Serial.println("3: LONG     - ~8km range, HIGH power (SF10, 20dBm)");
  Serial.println("4: EXTREME  - ~15km range, VERY HIGH power (SF12, 20dBm)");
  Serial.printf("Current Profile: %d ", cfg_loraProfile);
  switch(cfg_loraProfile) {
    case 1: Serial.println("(ECO)"); break;
    case 2: Serial.println("(BALANCED)"); break;
    case 3: Serial.println("(LONG)"); break;
    case 4: Serial.println("(EXTREME)"); break;
  }
  input = readInput("LoRa Profile (1-4)", String(cfg_loraProfile));
  if(input != "") {
    uint8_t profile = input.toInt();
    if(profile >= 1 && profile <= 4) {
      prefs.putUChar("lora_prf", profile);
      Serial.printf("LoRa Profile set to %d\n", profile);
    } else {
      Serial.println("Invalid! Keeping current.");
    }
  }

  Serial.printf("\nCurrent Packet Count: %d\n", currentPacketId);
  input = readInput("Reset Packet Counter to 0? (y/n)", "n");
  if(input == "y") {
    prefs.putUInt("pkt_cnt", 0);
    Serial.println("Packet Counter Reset to 0!");
  }

  Serial.printf("Current Gas Baseline: %.0f\n", current_baseline);
  input = readInput("Reset Baseline to Default? (y/n)", "n");
  if(input == "y") {
    prefs.putFloat("gas_base", DEFAULT_BASELINE);
    Serial.println("Baseline Reset!");
  }

  Serial.println("\nSaved. Restarting...");
  prefs.end();
  delay(1000);
  ESP.restart();
}

// AES-128-ECB encrypt the 48-byte packet (3 blocks) and send over LoRa
void encryptAndSend(SecurePacket* pkt) {
  mbedtls_aes_context aes;
  mbedtls_aes_init(&aes);

  uint8_t keyBytes[16];
  cfg_aesKey.getBytes(keyBytes, 17);
  mbedtls_aes_setkey_enc(&aes, keyBytes, 128);

  uint8_t input[48];
  uint8_t output[48];
  memcpy(input, pkt, 48);

  for(int i=0; i<3; i++) {
    mbedtls_aes_crypt_ecb(&aes, MBEDTLS_AES_ENCRYPT, input + (i*16), output + (i*16));
  }
  mbedtls_aes_free(&aes);

  LoRa.beginPacket();
  LoRa.write(output, 48);
  LoRa.endPacket();
}

// Parse ZH03B 32-byte Plantower-compatible UART frame.
// Header: 0x42 0x4D, then bytes 8-13 = atmospheric PM values (ug/m3).
// Falls back to CF=1 standard values (bytes 2-7) if atmospheric reads zero.
DustData readZH03B() {
  DustData d = {0, 0, 0};
  if (!zhSerial.available()) return d;
  byte buffer[32];
  unsigned long start = millis();
  while (millis() - start < 200 && zhSerial.available()) {
    if (zhSerial.read() == 0x42) {
      if (zhSerial.peek() == 0x4D) {
        zhSerial.read();
        if (zhSerial.available() >= 22) {
           zhSerial.readBytes(buffer, 22);
           d.pm1_0 = (buffer[8] << 8) + buffer[9];
           d.pm2_5 = (buffer[10] << 8) + buffer[11];
           d.pm10  = (buffer[12] << 8) + buffer[13];
           if (d.pm2_5 == 0 && (buffer[2] != 0 || buffer[3] != 0)) {
              d.pm1_0 = (buffer[2] << 8) + buffer[3];
              d.pm2_5 = (buffer[4] << 8) + buffer[5];
              d.pm10  = (buffer[6] << 7) + buffer[7];
           }
           return d;
        }
      }
    }
  }
  return d;
}
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
void loop() {}
